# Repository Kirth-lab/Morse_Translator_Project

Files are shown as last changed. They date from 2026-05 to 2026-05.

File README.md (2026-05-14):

# Morse Translator Project

Made by melluche and Kirth-lab, 1st-year students at ENSEA.
The Morse Translator project allows you to translate a Morse coded message by typing your message in the keypads. It also works in the opposite way : you can code your message in Morse language, and the alphabet coded message will show in the screen. 

In the repository, you may find all the PCB files, code and datasheets. We also left the 3D model of our case, where you can put your PCB, and fix the screen on the top of it. Feel free to explore it.

> At this state of the project, we don't know if the PCB works. We will keep you updated.

### Objectives :
- Translate a Morse coded message to an alphabet coded message by typing the touch "." and "-" on the keypads. After coding, the message will be shown on the screen and you will be able to read it.
- Translate an alphabet coded message to a Morse coded message using the keypads. After typing, a buzzer will play the *bips* of the message, and a LED will blink at the same time.

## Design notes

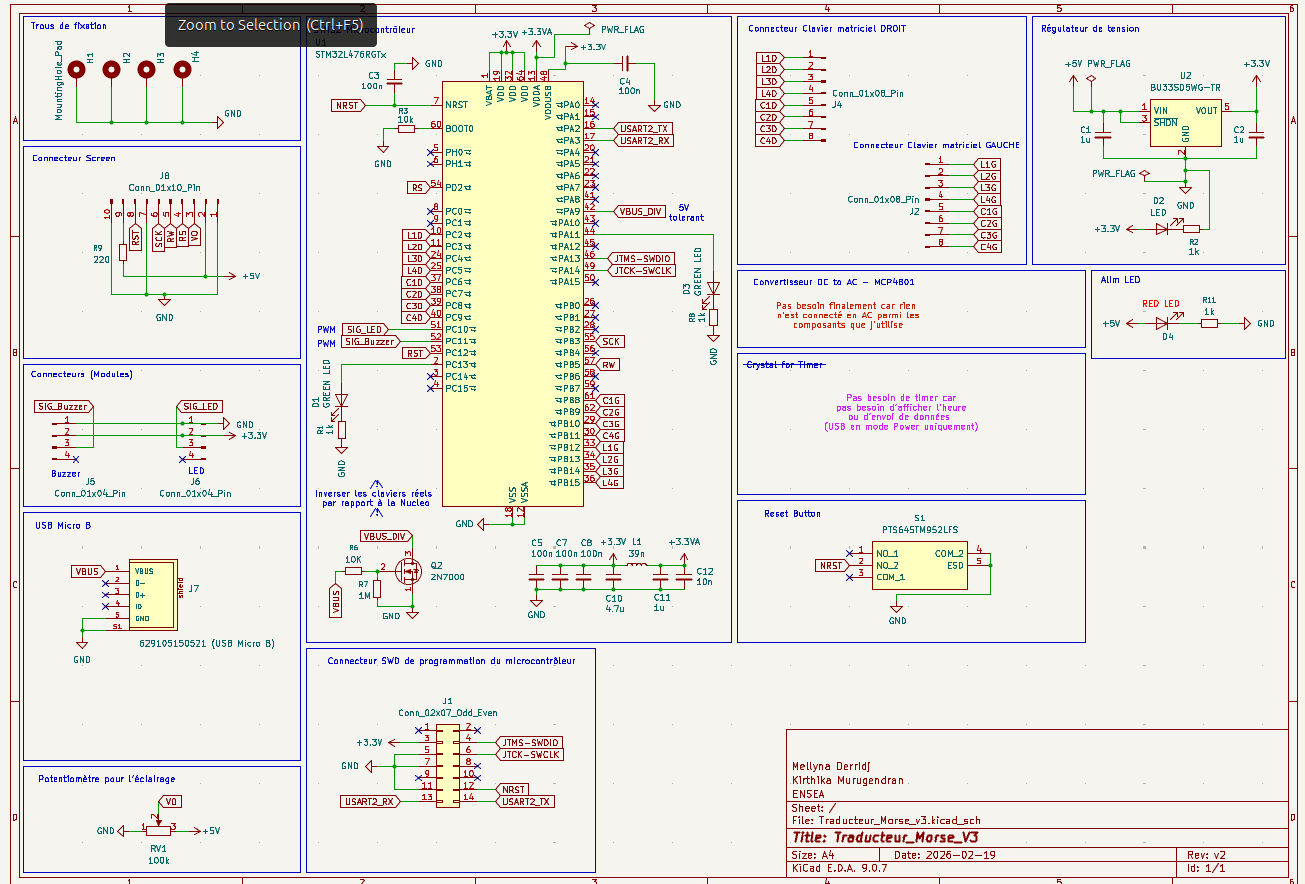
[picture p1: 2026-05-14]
PCB_Design/Schematics.png

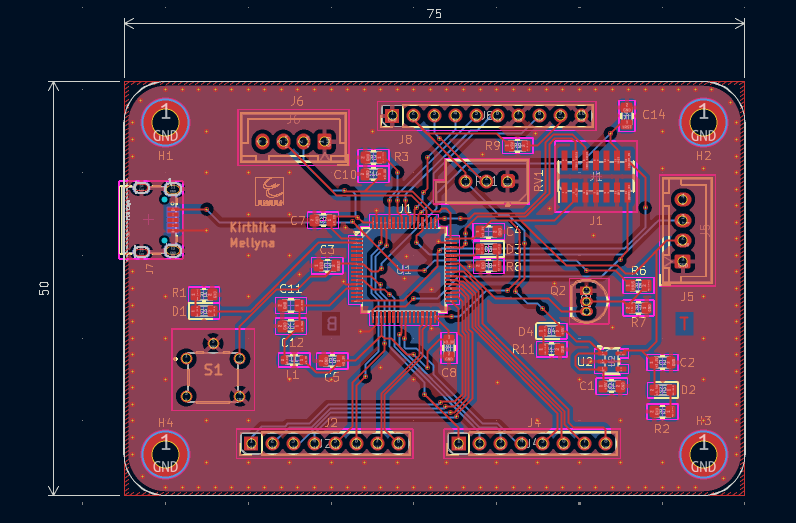
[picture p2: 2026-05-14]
PCB_Design/PCB_dimensions.png

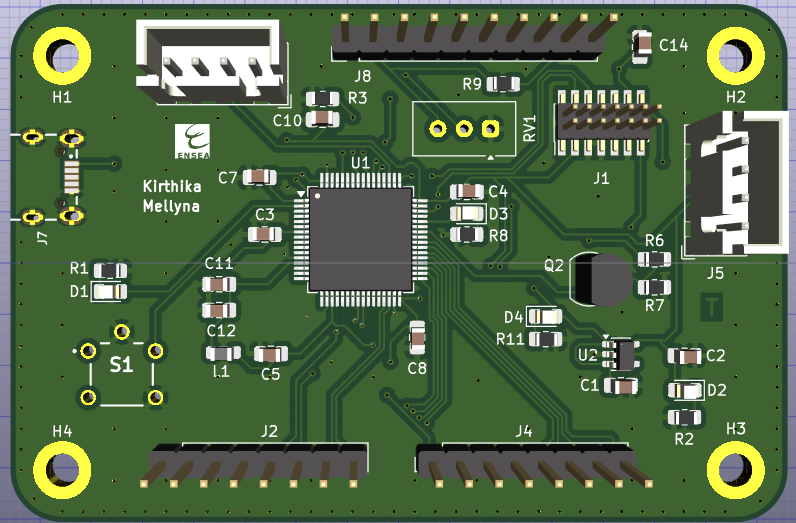
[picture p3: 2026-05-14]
PCB_Design/PCB_3D_Top.png

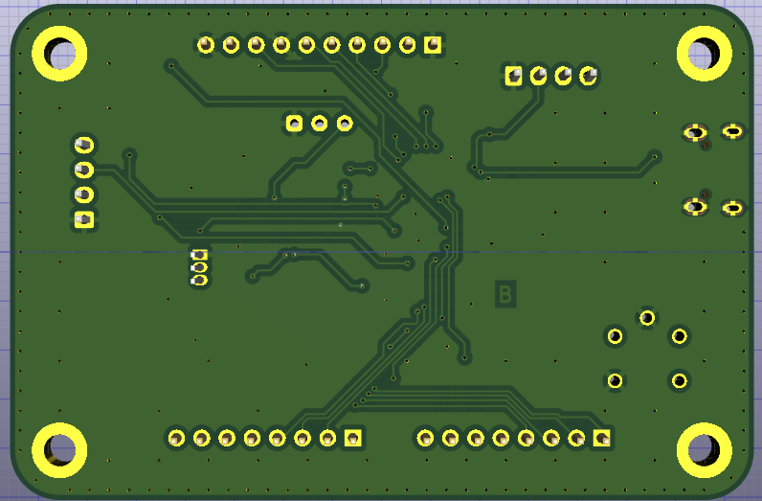
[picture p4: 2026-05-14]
PCB_Design/PCB_3D_Back.png

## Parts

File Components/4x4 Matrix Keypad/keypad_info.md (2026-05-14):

Here is a link where you can find how to use matrix keypads : 
- https://www.reddit.com/r/arduino/comments/565hje/how_to_read_a_4x4_keypad_using_just_one_arduino/?tl=fr
- https://www.electronicwings.com/sensors-modules/4x4-keypad-module

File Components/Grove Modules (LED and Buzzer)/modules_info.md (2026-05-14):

Here are the links where you can find the modules' specifications and its applications : 
- LED : https://wiki.seeedstudio.com/Grove-Red_LED/
- Buzzer : https://wiki.seeedstudio.com/Grove-Buzzer/

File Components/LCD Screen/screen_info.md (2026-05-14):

The screen we used is this one : https://www.dfrobot.com/product-240.html

You can use these links to learn how to use it : 
- https://blog.embeddedexpert.io/?p=2030
- https://lastminuteengineers.com/arduino-1602-character-lcd-tutorial/

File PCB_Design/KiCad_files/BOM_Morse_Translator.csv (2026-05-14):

Id | Designator | Footprint | Quantity | Designation | Supplier and ref
1 | C12 | C_0805_2012Metric_Pad1.18x1.45mm_HandSolder | 1 | 10n
2 | R6 | R_0805_2012Metric_Pad1.20x1.40mm_HandSolder | 1 | 10K
3 | J7 | 629105150521 | 1 | 629105150521 (USB Micro B)
4 | J5,J6 | JST_XH_B4B-XH-A_1x04_P2.50mm_Vertical | 2 | Conn_01x04_Pin
5 | C14,C5,C4,C8,C7,C3 | C_0805_2012Metric_Pad1.18x1.45mm_HandSolder | 6 | 100n
6 | J8 | PinHeader_1x10_P2.54mm_Vertical | 1 | Conn_01x10_Pin
7 | D1,D3 | LED_0805_2012Metric_Pad1.15x1.40mm_HandSolder | 2 | GREEN LED
8 | R7 | R_0805_2012Metric_Pad1.20x1.40mm_HandSolder | 1 | 1M
9 | C2,C1,C11 | C_0805_2012Metric_Pad1.18x1.45mm_HandSolder | 3 | 1u
10 | J4,J2 | PinHeader_1x08_P2.54mm_Vertical | 2 | Conn_01x08_Pin
11 | U1 | LQFP-64_10x10mm_P0.5mm | 1 | STM32L476RGTx
12 | D2 | LED_0805_2012Metric_Pad1.15x1.40mm_HandSolder | 1 | LED
13 | R3 | R_0805_2012Metric_Pad1.20x1.40mm_HandSolder | 1 | 10k
14 | D4 | LED_0805_2012Metric_Pad1.15x1.40mm_HandSolder | 1 | RED LED
15 | R8,R11,R1,R2 | R_0805_2012Metric_Pad1.20x1.40mm_HandSolder | 4 | 1k
16 | RV1 | Potentiometer_Vishay_T93XA_Horizontal | 1 | 100k
17 | C10 | C_0805_2012Metric_Pad1.18x1.45mm_HandSolder | 1 | 4.7u
18 | L1 | L_0805_2012Metric_Pad1.05x1.20mm_HandSolder | 1 | 39n
19 | R9 | R_0805_2012Metric_Pad1.20x1.40mm_HandSolder | 1 | 220
20 | U2 | SOT-23-5 | 1 | BU33SD5WG-TR
21 | Q2 | TO-92_Inline | 1 | 2N7000
22 | J1 | PinHeader_2x07_P1.27mm_Vertical_SMD | 1 | Conn_02x07_Odd_Even
23 | S1 | PTS645TM952LFS | 1 | PTS645TM952LFS

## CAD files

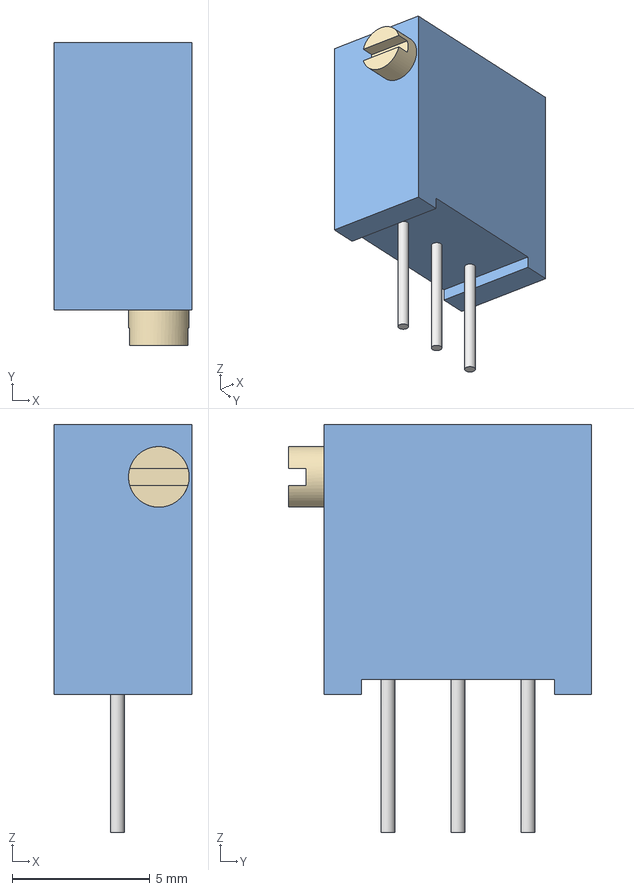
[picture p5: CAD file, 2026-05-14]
Components/Potentiometer/T93XA504KT20.stp
5.00 x 11.0 x 14.8 mm

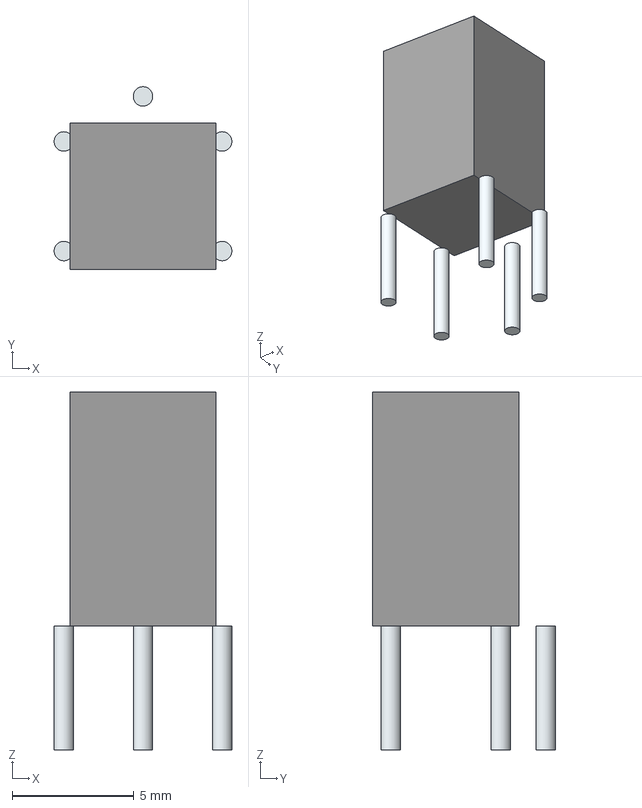
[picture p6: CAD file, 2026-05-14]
Components/Reset Switch/PTS645TM952LFS.stp
7.30 x 7.50 x 14.7 mm
Leads

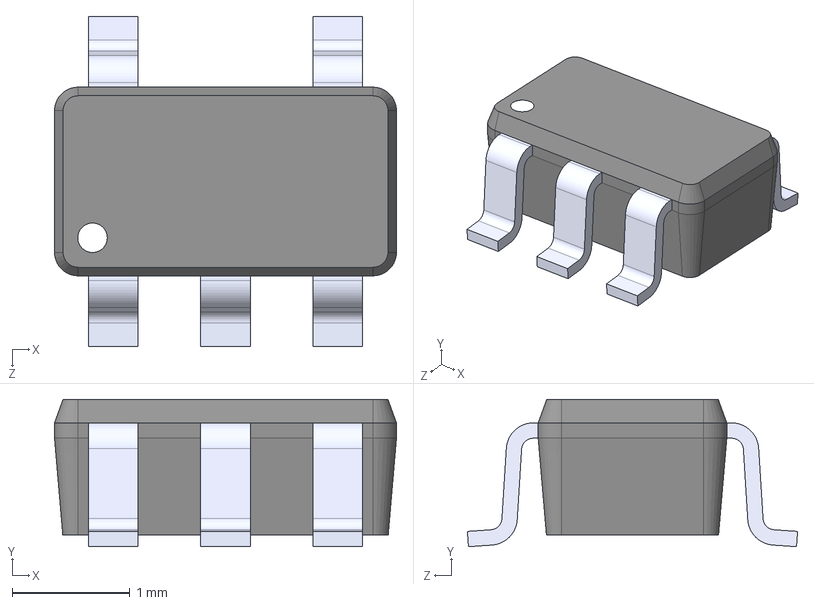
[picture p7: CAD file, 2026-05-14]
Components/Voltage Regulator (5V to 3.3V)/BU33SD5WG-TR.step
2.90 x 1.25 x 2.80 mm

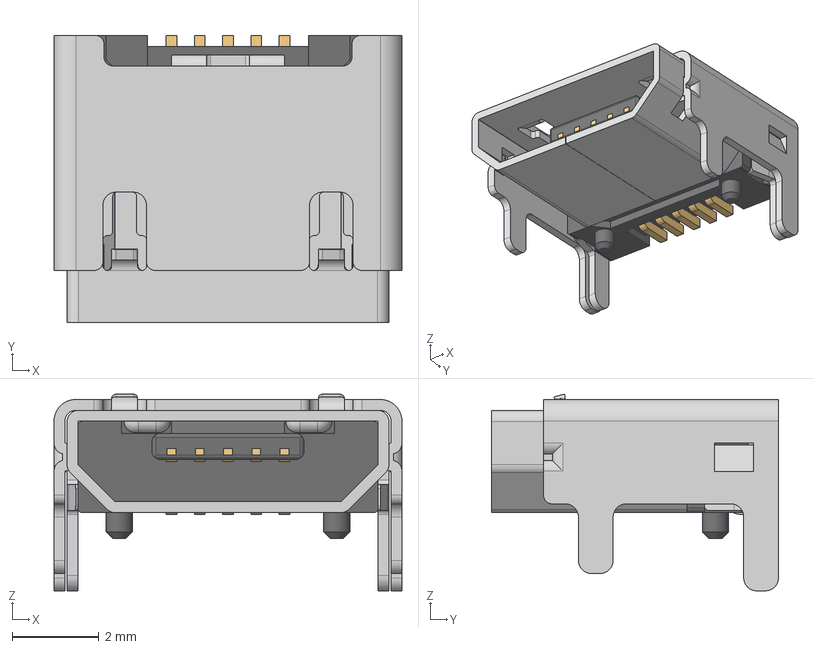
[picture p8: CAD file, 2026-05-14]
Components/USB B Micro/629105150521.stp
8.00 x 6.60 x 4.52 mm
629105150521_Housing
629105150521_Pin1 x 4
629105150521_Pin2
629105150521_Shielding2
629105150521_Shielding

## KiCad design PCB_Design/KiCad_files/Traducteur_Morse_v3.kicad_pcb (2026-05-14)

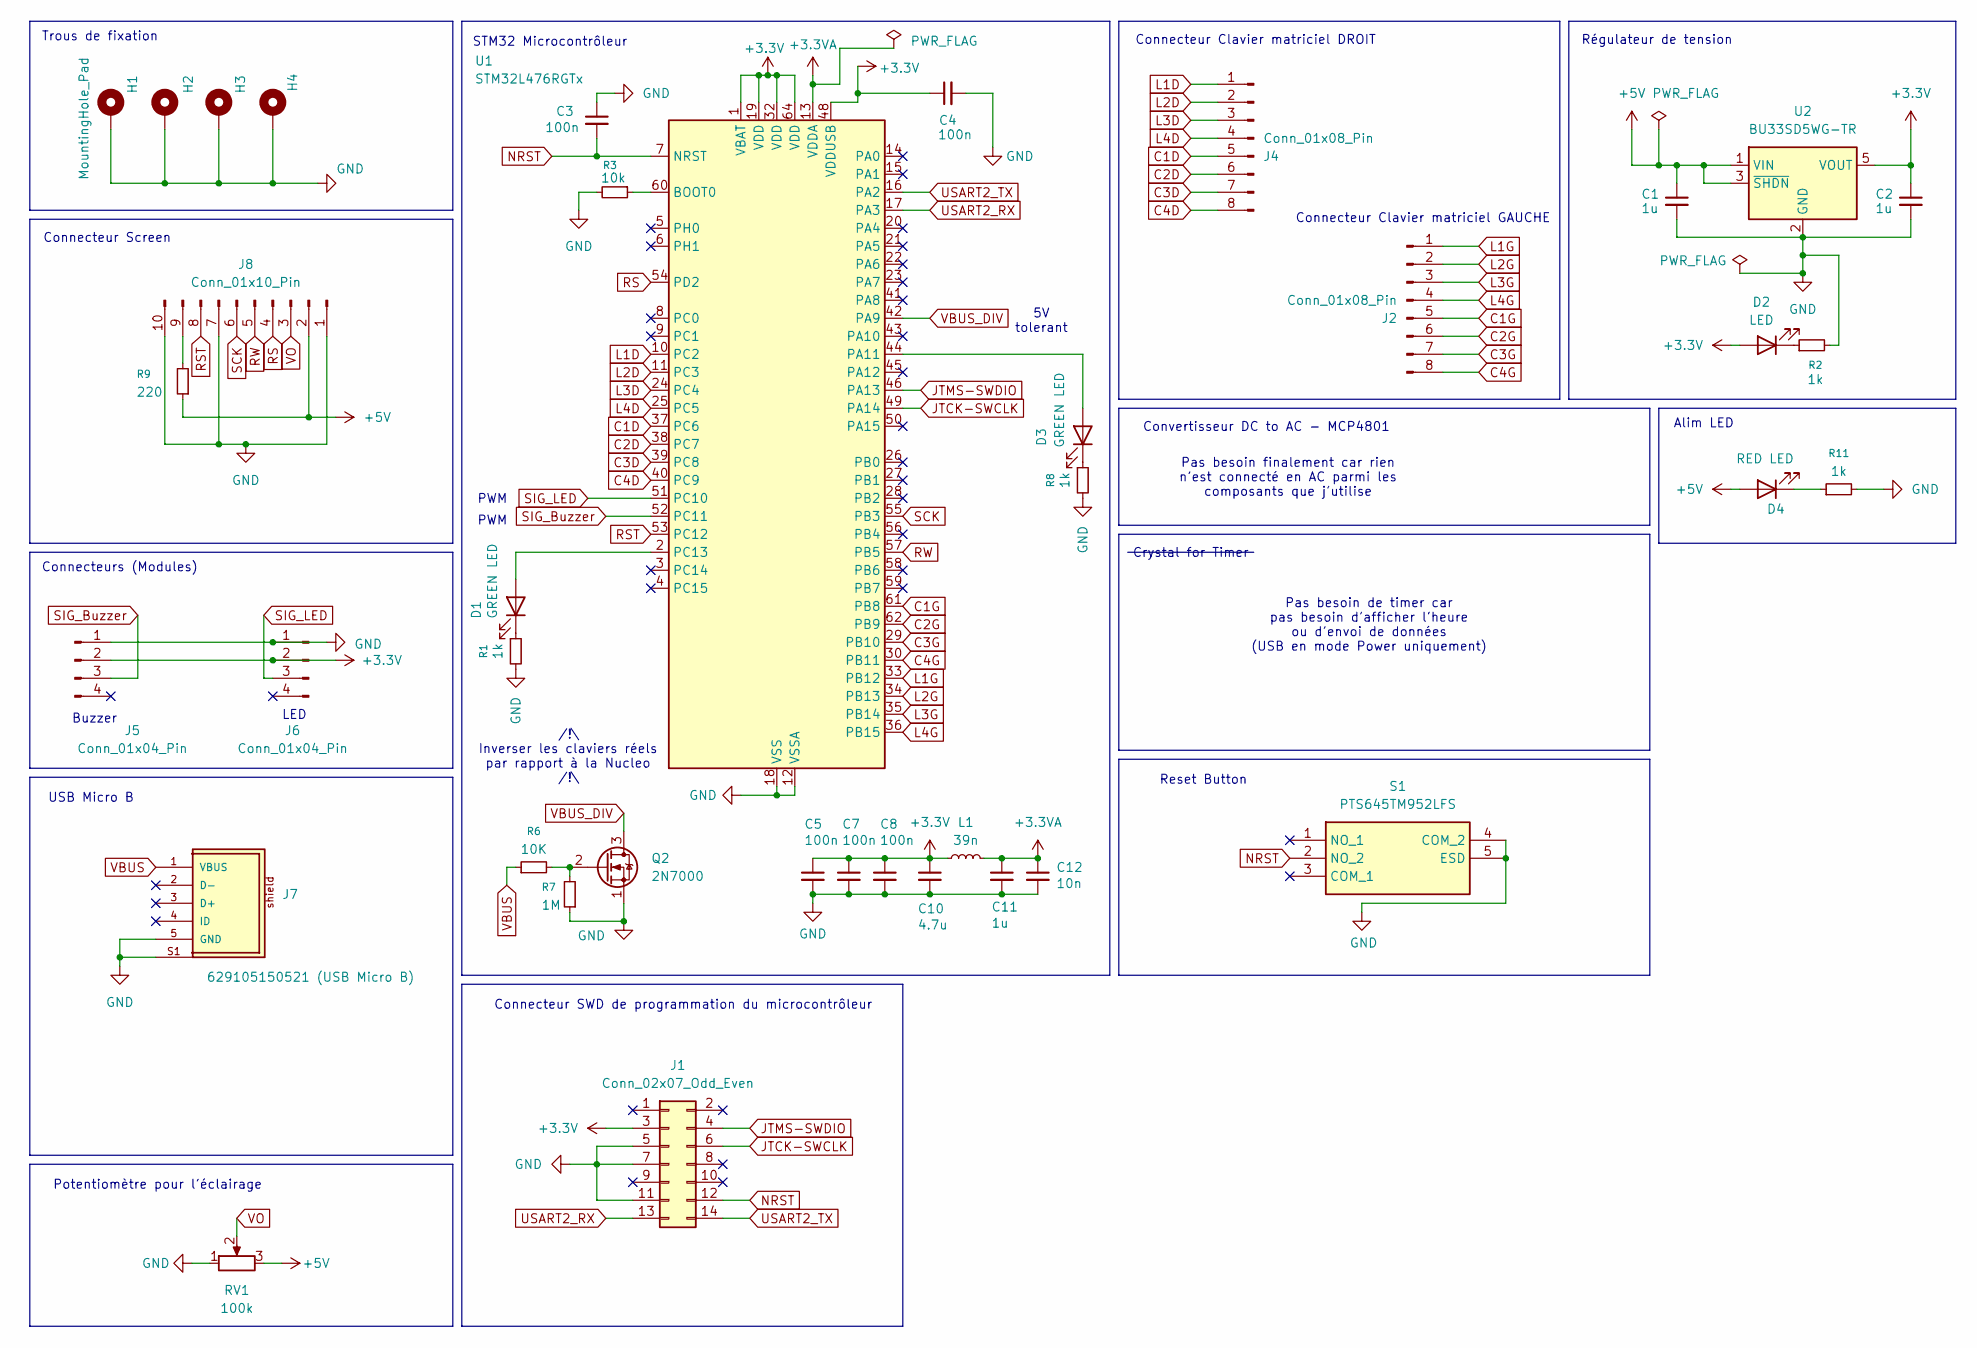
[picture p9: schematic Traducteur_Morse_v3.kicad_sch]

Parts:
C1, C2, C11: 1u; C_0805_2012Metric_Pad1.18x1.45mm_HandSolder
C3, C4, C5, C7, C8: 100n; C_0805_2012Metric_Pad1.18x1.45mm_HandSolder
C10: 4.7u; C_0805_2012Metric_Pad1.18x1.45mm_HandSolder
C12: 10n; C_0805_2012Metric_Pad1.18x1.45mm_HandSolder
D1, D3: GREEN LED; LED_0805_2012Metric_Pad1.15x1.40mm_HandSolder
D2: LED; LED_0805_2012Metric_Pad1.15x1.40mm_HandSolder
D4: RED LED; LED_0805_2012Metric_Pad1.15x1.40mm_HandSolder
H1, H2, H3, H4: MountingHole_Pad; MountingHole_3.2mm_M3_DIN965_Pad
J1: Conn_02x07_Odd_Even; PinHeader_2x07_P1.27mm_Vertical_SMD
J2, J4: Conn_01x08_Pin; PinHeader_1x08_P2.54mm_Vertical
J5, J6: Conn_01x04_Pin; JST_XH_B4B-XH-A_1x04_P2.50mm_Vertical
J7: 629105150521 (USB Micro B); 629105150521
J8: Conn_01x10_Pin; PinHeader_1x10_P2.54mm_Vertical
L1: 39n; L_0805_2012Metric_Pad1.05x1.20mm_HandSolder
Q2: 2N7000; TO-92_Inline
R1, R2, R8, R11: 1k; R_0805_2012Metric_Pad1.20x1.40mm_HandSolder
R3: 10k; R_0805_2012Metric_Pad1.20x1.40mm_HandSolder
R6: 10K; R_0805_2012Metric_Pad1.20x1.40mm_HandSolder
R7: 1M; R_0805_2012Metric_Pad1.20x1.40mm_HandSolder
R9: 220; R_0805_2012Metric_Pad1.20x1.40mm_HandSolder
RV1: 100k; Potentiometer_Vishay_T93XA_Horizontal
S1: PTS645TM952LFS; Manufacturer_Part_Number PTS645TM952LFS; Mouser Part Number 611-PTS645TM95LFS
U1: STM32L476RGTx; LQFP-64_10x10mm_P0.5mm
U2: BU33SD5WG-TR; SOT-23-5

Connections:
+3.3V: C2.1, C4.1, C5.1, C7.1, C8.1, C10.1, D2.2 (A), J1.3, J5.2, J6.2, L1.1, U1.1 (VBAT), U1.19 (VDD), U1.32 (VDD), U1.48 (VDDUSB), U1.64 (VDD), U2.5 (VOUT)
+3.3VA: C11.1, C12.1, L1.2, U1.13 (VDDA)
+5V: C1.1, D4.2 (A), J8.2, R9.1, RV1.3, U2.1 (VIN), U2.3 (~SHDN)
C1D: J4.5, U1.37 (PC6)
C1G: J2.5, U1.61 (PB8)
C2D: J4.6, U1.38 (PC7)
C2G: J2.6, U1.62 (PB9)
C3D: J4.7, U1.39 (PC8)
C3G: J2.7, U1.29 (PB10)
C4D: J4.8, U1.40 (PC9)
C4G: J2.8, U1.30 (PB11)
GND: C1.2, C2.2, C3.1, C4.2, C5.2, C7.2, C8.2, C10.2, C11.2, C12.2, H1.1, H2.1, H3.1, H4.1, J1.5, J1.7, J1.11, J5.1, J6.1, J7.5 (GND), J7.S1, J7.S2, J7.S3, J7.S4, J8.1, J8.7, J8.10, Q2.1 (S), R1.2, R2.2, R3.2, R7.1, R8.2, R11.2, RV1.1, S1.4 (COM_2), S1.5 (ESD), U1.12 (VSSA), U1.18 (VSS), U1.31 (VSS), U1.47 (VSS), U1.63 (VSS), U2.2 (GND); also elsewhere on the board
JTCK-SWCLK: J1.6, U1.49 (PA14)
JTMS-SWDIO: J1.4, U1.46 (PA13)
L1D: J4.1, U1.10 (PC2)
L1G: J2.1, U1.33 (PB12)
L2D: J4.2, U1.11 (PC3)
L2G: J2.2, U1.34 (PB13)
L3D: J4.3, U1.24 (PC4)
L3G: J2.3, U1.35 (PB14)
L4D: J4.4, U1.25 (PC5)
L4G: J2.4, U1.36 (PB15)
NRST: C3.2, J1.12, S1.2 (NO_2), U1.7 (NRST); also elsewhere on the board
unnamed: D1.2 (A), U1.2 (PC13)
unnamed: D1.1 (K), R1.1
unnamed: D2.1 (K), R2.1
unnamed: D3.2 (A), U1.44 (PA11)
unnamed: D3.1 (K), R8.1
unnamed: D4.1 (K), R11.1
unnamed: J8.9, R9.2
unnamed: Q2.2 (G), R6.2, R7.2
unnamed: R3.1, U1.60 (BOOT0)
RS: J8.4, U1.54 (PD2)
RST: J8.8, U1.53 (PC12)
RW: J8.5, U1.57 (PB5)
SCK: J8.6, U1.55 (PB3)
SIG_Buzzer: J5.3, U1.52 (PC11)
SIG_LED: J6.3, U1.51 (PC10)
USART2_RX: J1.13, U1.17 (PA3)
USART2_TX: J1.14, U1.16 (PA2)
VBUS: J7.1 (VBUS), R6.1
VBUS_DIV: Q2.3 (D), U1.42 (PA9)
VO: J8.3, RV1.2

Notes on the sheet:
Connecteur Clavier matriciel DROIT
Crystal for Timer
/!\ Inverser les claviers réels par rapport à la Nucleo /!\
Régulateur de tension
PWM
Reset Button
LED
Connecteur Screen
Connecteurs (Modules)
Pas besoin finalement car rien n'est connecté en AC parmi les composants que j'utilise
Connecteur Clavier matriciel GAUCHE
Pas besoin de timer car pas besoin d'afficher l'heure ou d'envoi de données (USB en mode Power uniquement)
Trous de fixation
Alim LED
5V tolerant
Convertisseur DC to AC - MCP4801
USB Micro B
Buzzer
STM32 Microcontrôleur
Connecteur SWD de programmation du microcontrôleur
Potentiomètre pour l'éclairage

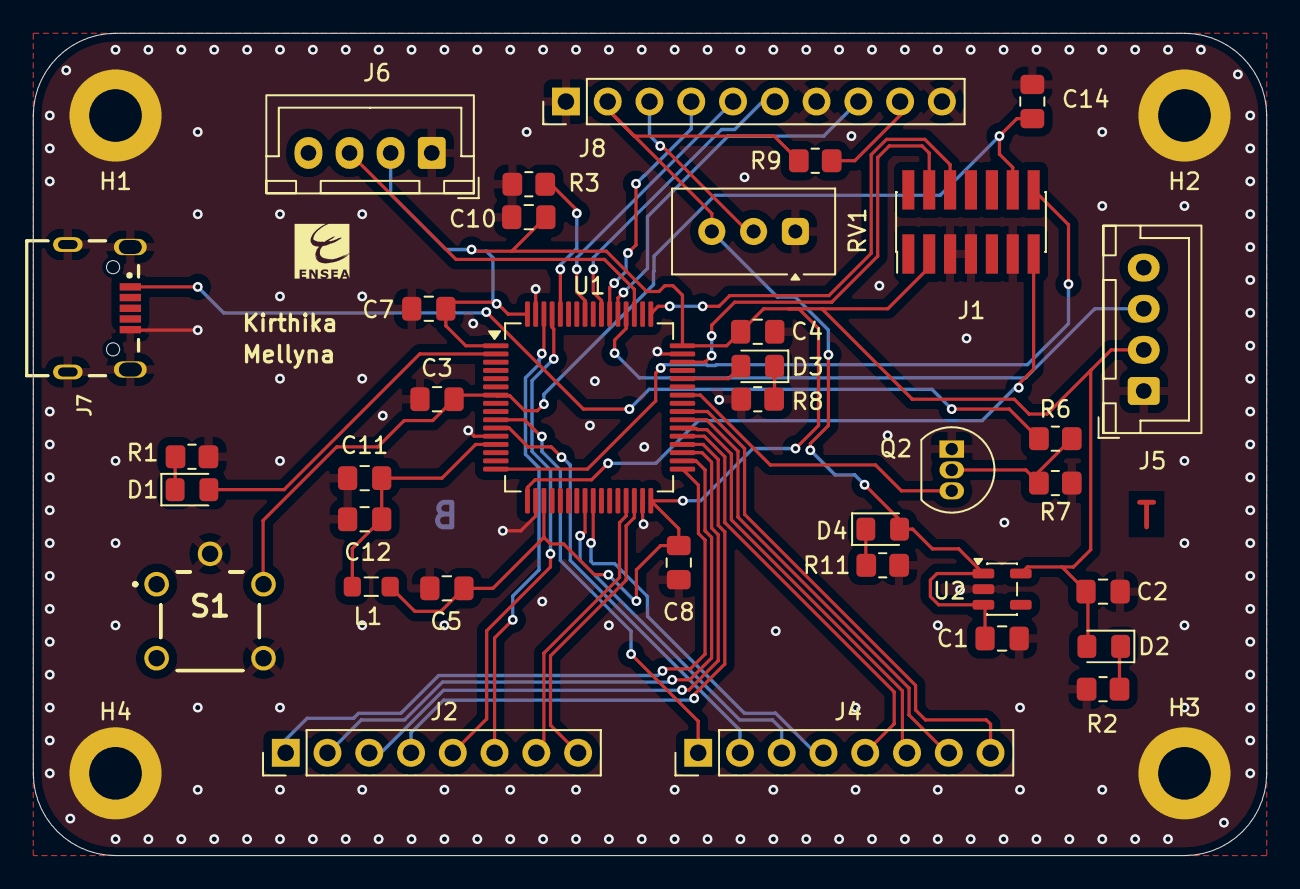
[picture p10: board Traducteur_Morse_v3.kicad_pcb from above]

Board: 2 copper layers, 75.0 x 50.0 mm, 40 parts (0 on the bottom side), 43 nets.

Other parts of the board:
C14: 100n; C_0805_2012Metric_Pad1.18x1.45mm_HandSolder

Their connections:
GND: C14.2; also elsewhere on the board
NRST: C14.1; also elsewhere on the board
